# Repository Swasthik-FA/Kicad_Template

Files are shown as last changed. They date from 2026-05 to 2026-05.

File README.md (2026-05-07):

<!--PCB_BLOCK-->
<table align="center">
  <tr>
    <td align="center">
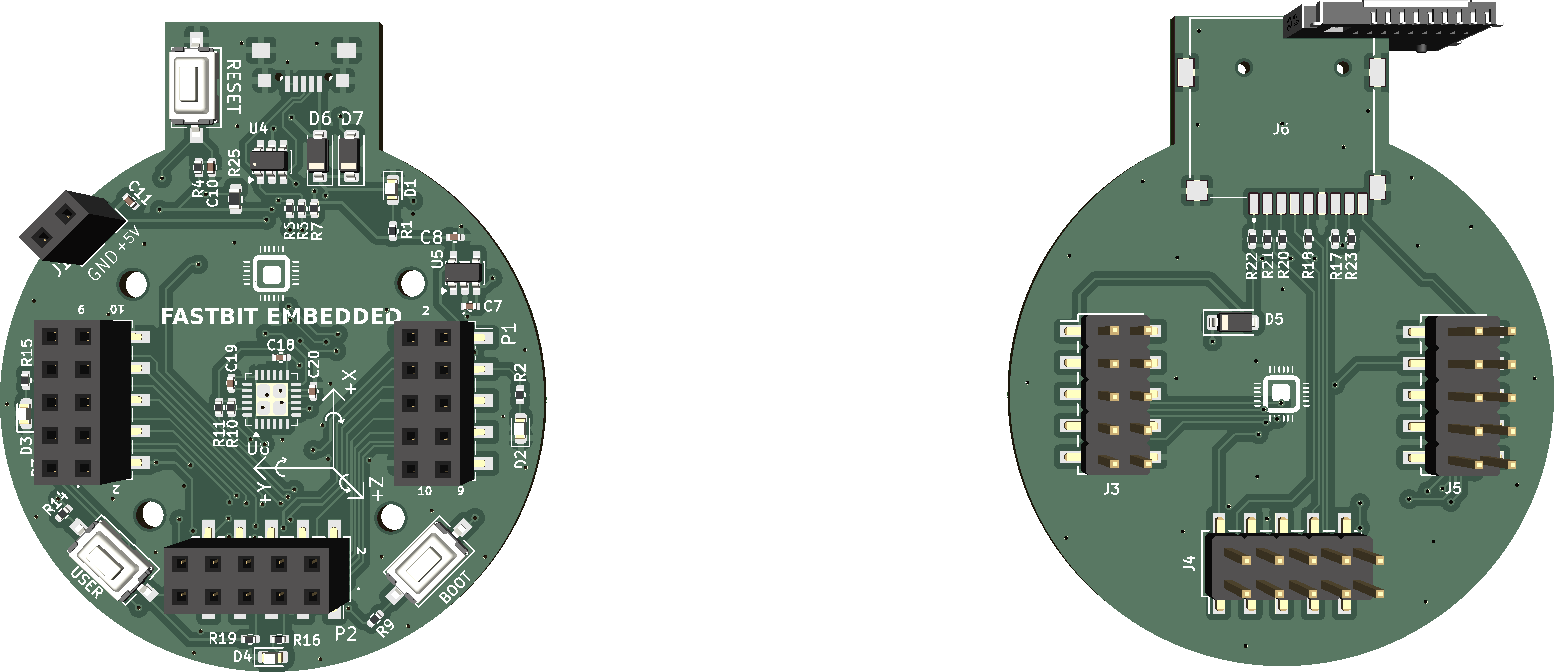
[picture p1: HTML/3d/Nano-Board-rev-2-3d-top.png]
Front
      
      <br><sub><b>Front</b></sub>
    </td>
    <td align="center">
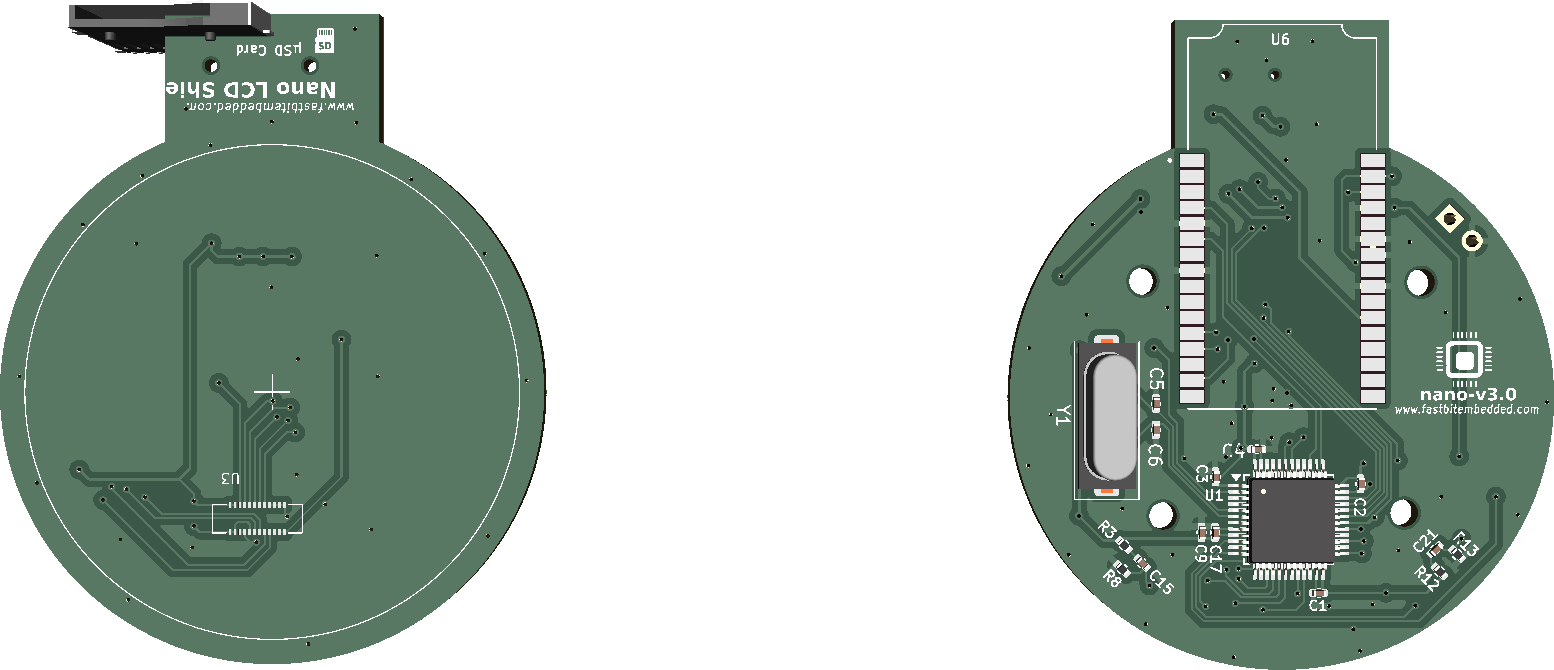
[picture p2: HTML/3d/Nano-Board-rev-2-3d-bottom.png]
Back
      
      <br><sub><b>Back</b></sub>
    </td>
  </tr>
</table>

***

## SPECIFICATIONS

| Parameter | Value |
| --- | --- |
| Dimensions | 125.74 x 53.08 mm |
<!--/PCB_BLOCK-->

***

## DIRECTORY STRUCTURE

    .
    ├─ .github/workflows  # CI pipeline (feature push, PR gates, release)
    ├─ HTML               # Generated reports / Pages site (CI output)
    ├─ config             # KiBot YAML configs and report templates
    │  ├─ kibot           # Orchestrator + per-output YAMLs
    │  └─ web             # Themed CSS and Three.js 3D viewer template
    ├─ docs               # Project images and documentation assets
    ├─ hardware           # KiCad project (source of truth)
    ├─ manufacturing      # Auto-generated fabrication artifacts
    └─ scripts            # Helper scripts (rename project, GLB export)

<p align="center" width="100%">
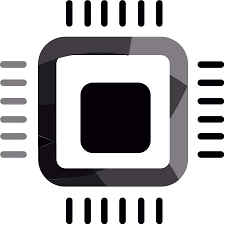
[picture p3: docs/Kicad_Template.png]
  
</p>

<h1 align="center"><!--REPO_NAME-->Kicad_Template<!--/REPO_NAME--></h1>

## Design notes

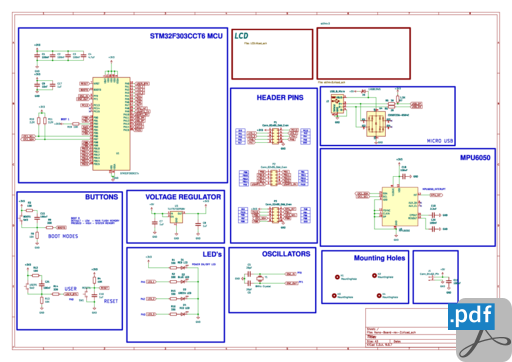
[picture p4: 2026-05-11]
HTML/HTML/images/cat_pdf_schematic_Nano-Board-rev-2-schematic.png

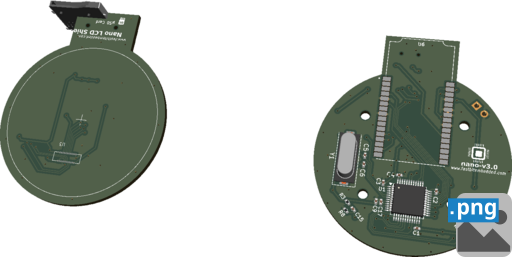
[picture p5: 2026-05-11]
HTML/HTML/images/cat_png_3d_angled_bottom_Nano-Board-rev-2-3d-angled-bottom.png

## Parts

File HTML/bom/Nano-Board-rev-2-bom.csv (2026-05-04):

Reference | Value | Footprint | Quantity | LCSC Part # | MPN | Manufacturer
BOOT1 | SW3 | SW_Tactile_SPST_NO_Straight_CK_PTS636Sx25SMTRLFS | 1 | C318938 | TS1101-C-W | C318936 TS1101-C-W
C5 C6 | 20pF | C_0402_1005Metric | 2 | C1554 | 0402CG200J50 0NT | FH (Guangdong Fenghua Advanced Tech 0402CG200J500NT
C19 | 2.2nF | C_0402_1005Metric | 1 | C338130 | 0402B222K500CT | Walsin Tech Corp 0402B222K500CT
C9 | 10nF | C_0402_1005Metric | 1 | C60133 | CC0402KRX7R9BB | YAGEO CC0402KRX7R9BB103
C1 C2 C3 C11 C15 C18 C20 C21 | 100nF | C_0402_1005Metric | 8 | C48579247 | TCC0402X5R1 04Z160A | CCTC 0402X7R104K160NT
C7 C8 C10 C17 | 1uF | C_0402_1005Metric | 4 | C7503519 | CL05A105KP5NNNC | CGA0402X5R105K6R3GT Samsung
C4 | 4.7uF | C_0402_1005Metric | 1 | C48579247 | TCC0402X5R4 75M6R3AT | CCTC 0402X7R104K160NT
D5 D6 D7 | 1N5819WS | D_SOD-123 | 3 | C191023 |  | 1N5819WS
D2 | BLUE LED | LED_0603_1608Metric | 1 | C165977 | BLHB337A-AV-TRB | BrtLed(Bright LED Elec) BL-HB337A-AV-TRB
D3 | GREEN LED | LED_0603_1608Metric | 1 | C434449 | SZYY0402YG | Yongyu Photoelectric SZYY0402YG
D1 D4 | RED LED | LED_0603_1608Metric | 2 | C165980 | BLHUB37A-AV-TRB | BrtLed(Bright LED Elec) BL-HUB37A-AV-TRB
J1 | Conn_01x02_Pin | PinSocket_1x02_P2.54mm_Vertical | 1
J3 J4 J5 | Conn_02x05_Odd_Even | PinHeader_2x05_P2.54mm_Vertical_SMD | 3 | C3294463 | PZ254-2-05-S | HCTL PZ254-2-05-S
J6 | Micro_SD_Card_Det1 | CUI_MSD-1-A | 1 | C52750848 | MLD-TF PUSH-H18 | MLD-TF PUSH-H18
J2 | USB_B_Micro | micro_USB | 1 | C25503144 | KH2.54FH1X12P-H8.5 | HCTL 051T-4BH89-S
P1 P2 P3 | Conn_02x05_Odd_Even | PinSocket_2x05_P2.54mm_Vertical_SMD | 3 | C843271 | 2.54-2*5P | Liansheng 2.54-2*5P
R25 | 0 | R_0603_1608Metric | 1
R5 R6 | 20 | R_0402_1005Metric | 2 | C138031 | RC0402FR-0720RL | YAGEO RC0402FR-0720RL
R3 R12 | 100 | R_0402_1005Metric | 2 | C3017466 | SCR0402J100R | VO SCR0402J100R
R1 R2 R9 R14 R15 R16 | 330 | R_0402_1005Metric | 6 | C2906929 | FRC0402J331 TS | FOJAN FRC0402J331 TS
R7 | 1.5K | R_0402_1005Metric | 1 | C2929900 | FRC0402J152TS | FOJAN FRC0402J152TS
R10 R11 | 2.2K | R_0402_1005Metric | 2 | C100309 | CR0402FF2201G | LIZ Elec CR0402FF2201G
R8 R13 R17 R18 R19 R20 R21 R22 R23 | 10K | R_0402_1005Metric | 9 | C51035904 | SCR0402F10K | VO CL0402JN10KP
R4 | 10K | R_0402_1005Metric | 1 | C51035904 | SCR0402J100K | VO CL0402JN10KP
RESET1 | SW1 | SW_Tactile_SPST_NO_Straight_CK_PTS636Sx25SMTRLFS | 1 | C318938 | TS1101-C-W | C318936 TS1101-C-W
U4 | CDSOT236-0504C | SOT-23-6 | 1 | C41409337 | CDSOT236- 0504C | Leiditech CDSOT236-0504C-ES
U8 | MPU6050 | Mpu6050 | 1 |  | MPU-6050 | InvenSense MPU-6050
U6 | STLINK-V3MODS | MODULE_STLINK-V3MODS | 1 |  |  | ST Microelectronics
U1 | STM32F303CCTx | LQFP-48_7x7mm_P0.5mm | 1 | C81523 | STM32F303CC T6 | STMicroelectro nics STM32F303CC T6
U5 | TLV75733PDBV | SOT-23-5 | 1 | C485517 |  | TLV75733PDBVR
U3 | ~ | OK-24F024-04 | 1
USER1 | SW2 | SW_Tactile_SPST_NO_Straight_CK_PTS636Sx25SMTRLFS | 1 | C318938 | TS1101-C-W | C318936 TS1101-C-W
Y1 | 8MHz Crystal | Crystal_SMD_HC49-SD | 1 | C12674 | X49SM8MSD2 | YXC X49SM8MSD2SC

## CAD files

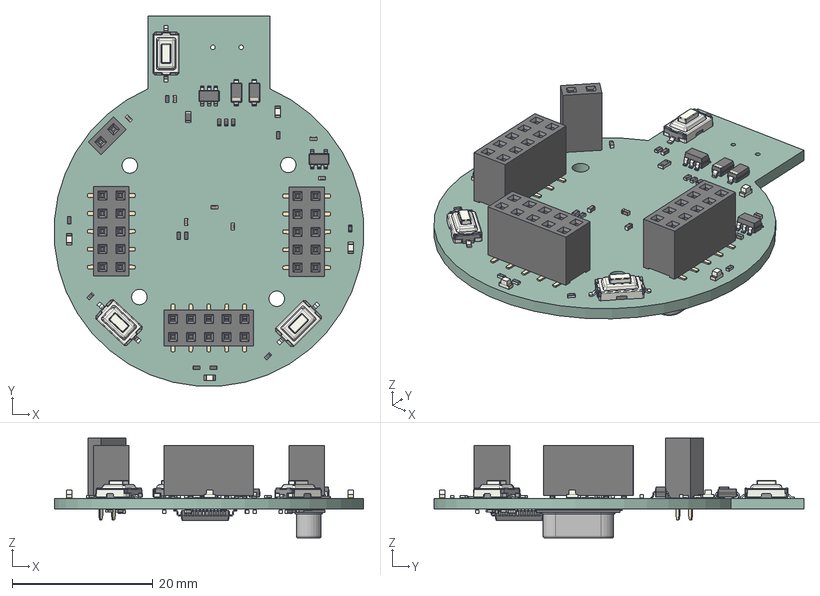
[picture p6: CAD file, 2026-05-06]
HTML/3d/Nano-Board-rev-2.step
43.9 x 52.5 x 14.2 mm
LED_0603_1608Metric x 4
R_0402_1005Metric x 17
C_0402_1005Metric x 17
R_0603_1608Metric
PinSocket_2x05_P2.54mm_Vertical_SMD x 3
SW_Tactile_SPST_NO_Straight_CK_PTS636Sx25SMTRLFS x 3
SOT-23-6
D_SOD-123 x 2
SOT-23-5
PinSocket_1x02_P2.54mm_Vertical
Crystal_SMD_HC49-SD
LQFP-48_7x7mm_P0.5mm
kibot_6w4liwqz_PCB

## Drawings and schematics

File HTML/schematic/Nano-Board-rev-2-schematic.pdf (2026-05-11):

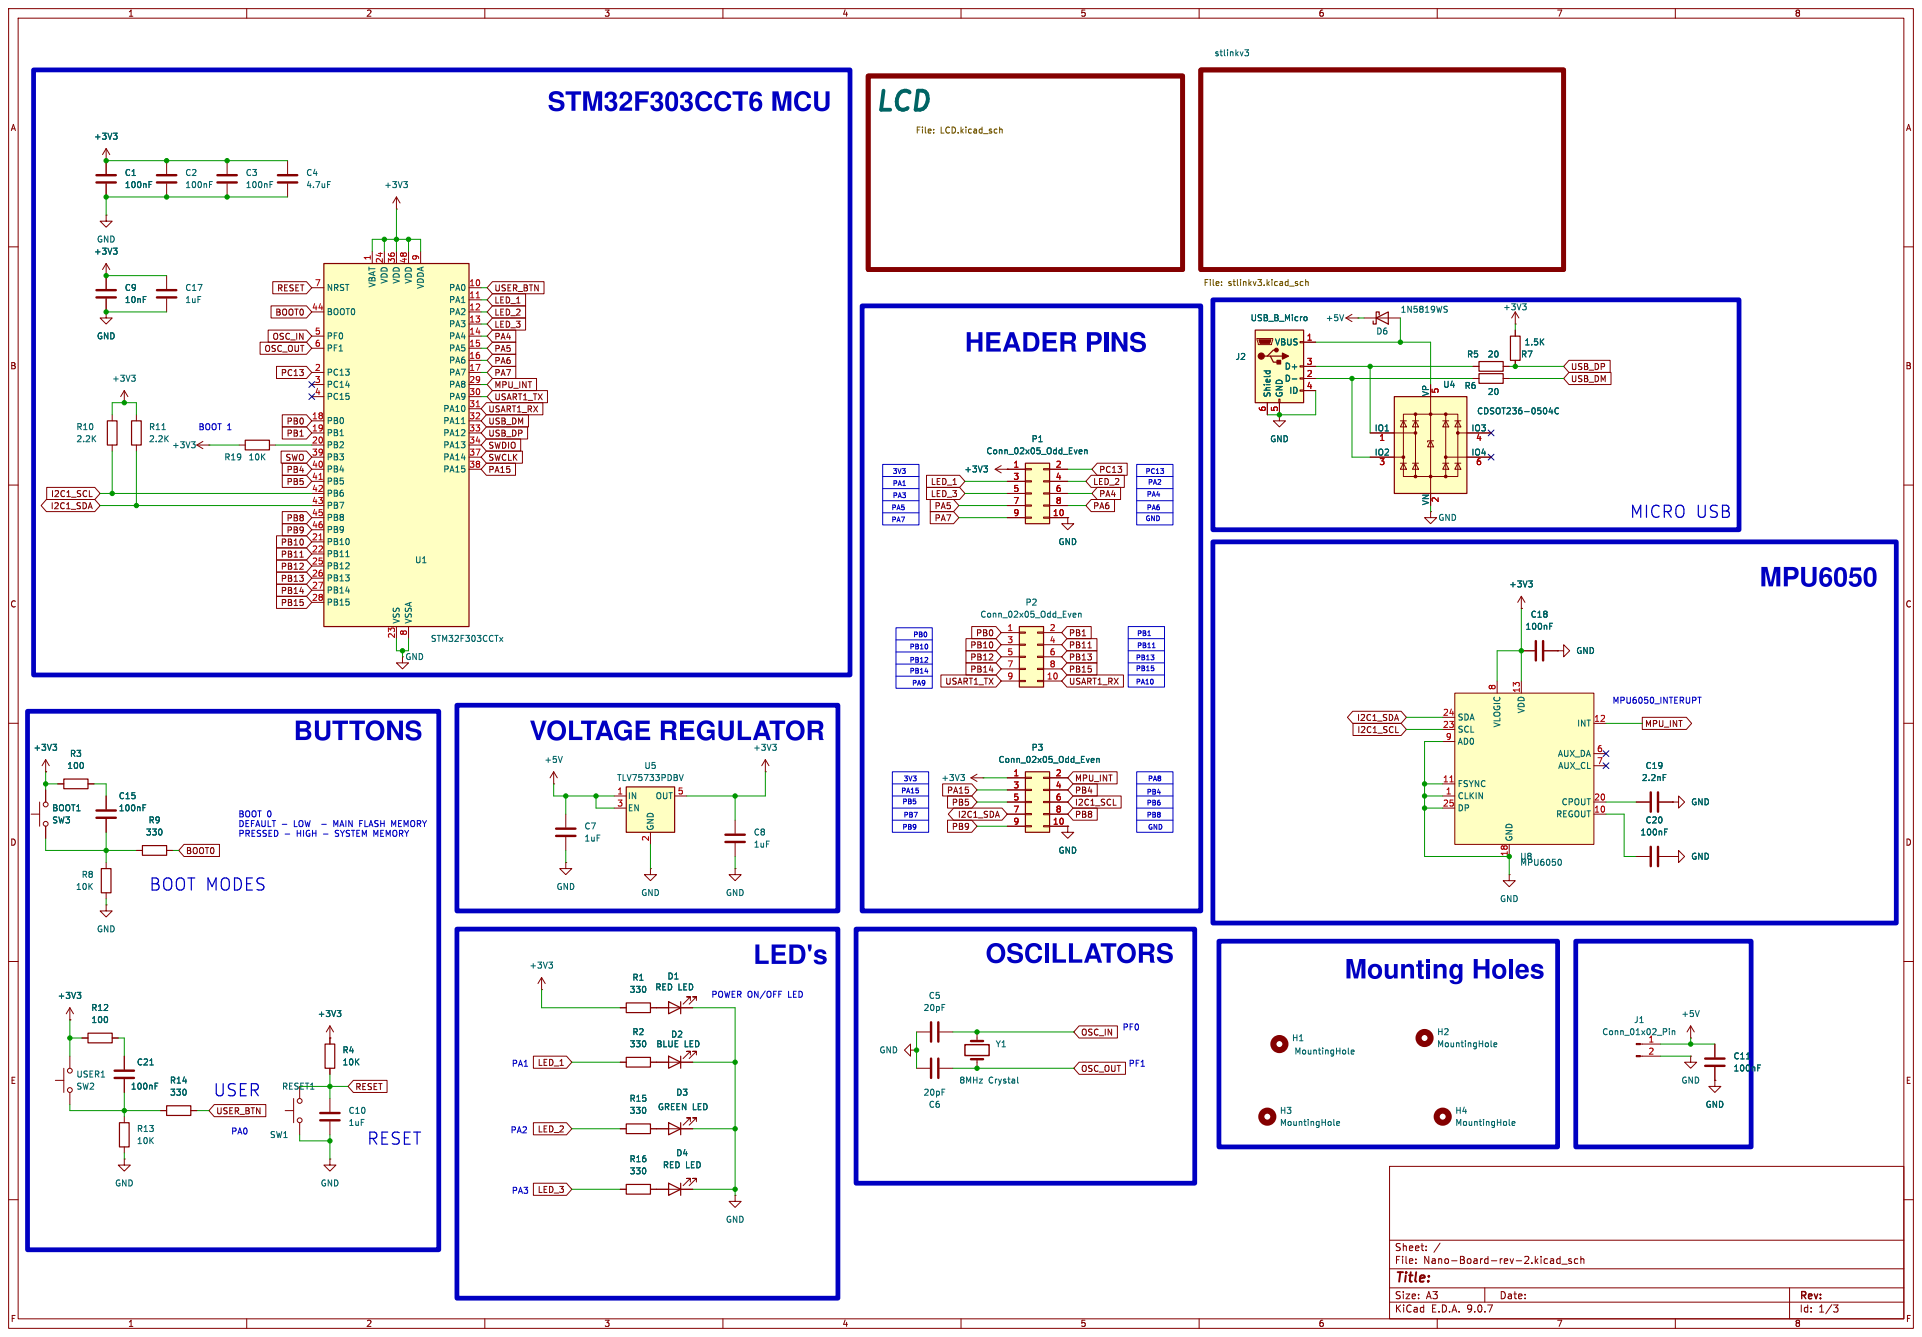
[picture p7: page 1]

PA2 BOOT 0 DEFAULT - LOW - MAIN FLASH MEMORY

PA6 POWER ON/OFF LED

8 VDD 13 U8 MPU6050
INT 12 AUX_DA 6 AUX_CL 7 CPOUT 20 REGOUT 10 VLOGIC

PRESSED - HIGH - SYSTEM MEMORY BOOT MODES
10K GND

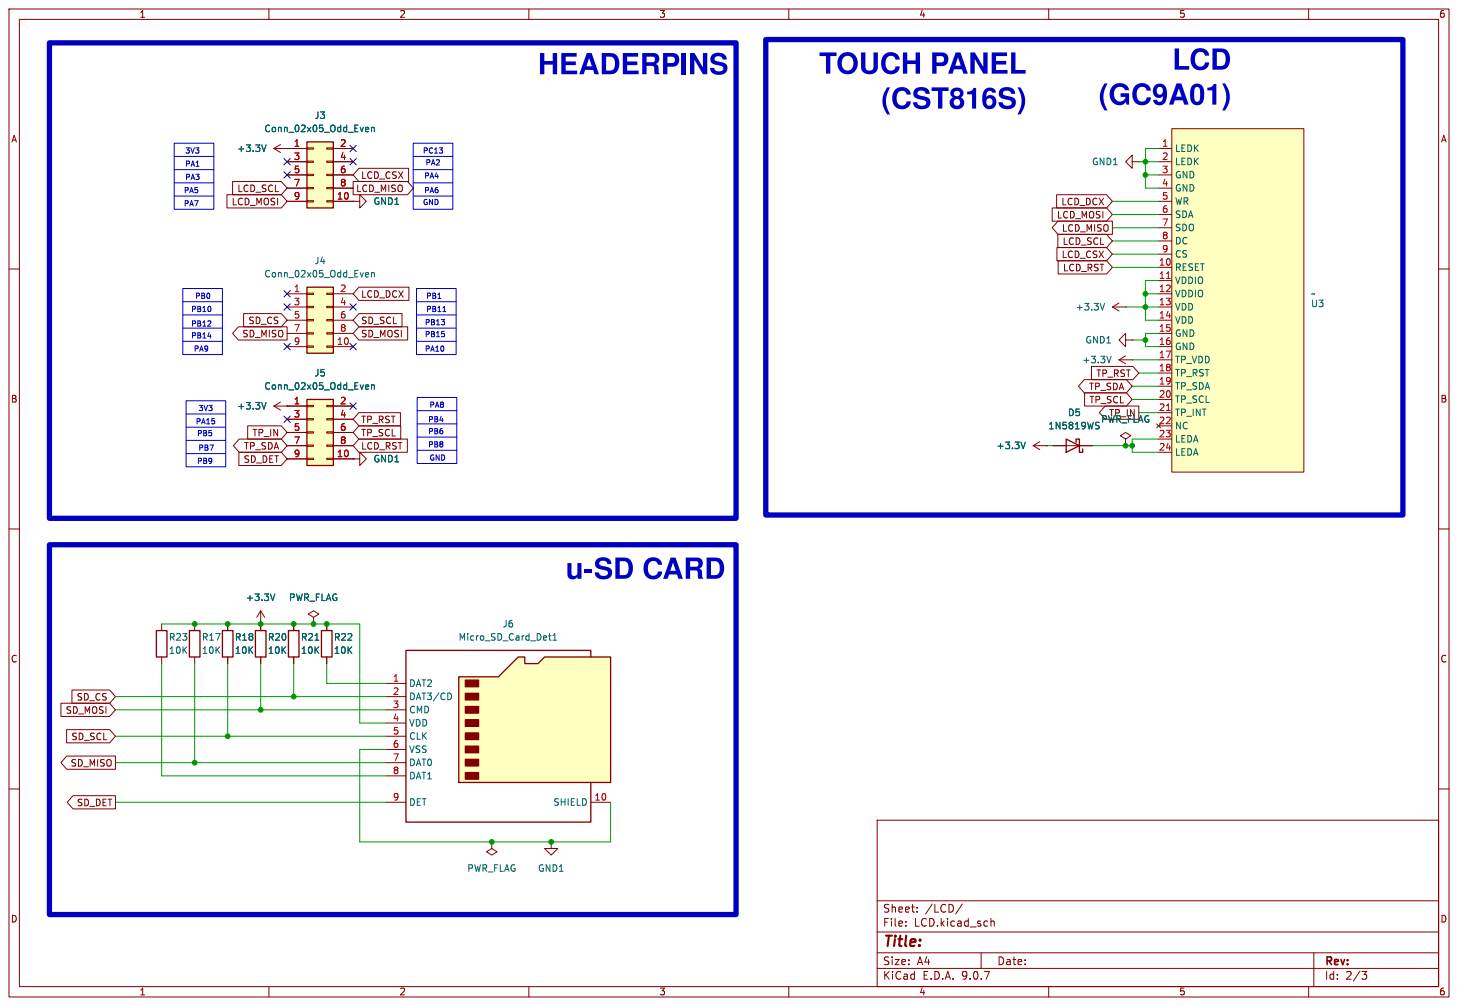
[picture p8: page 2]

Id: 2/3 Title: File: LCD.kicad_sch Sheet: /LCD/

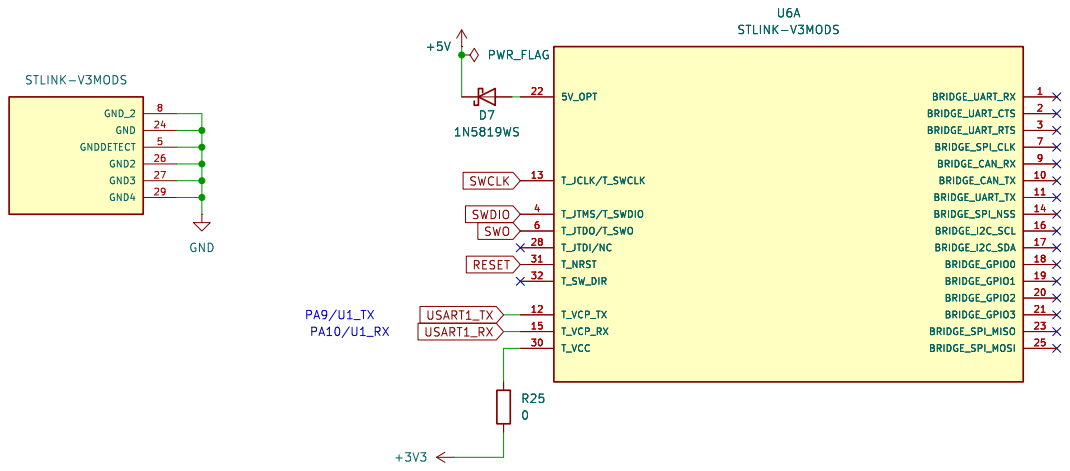
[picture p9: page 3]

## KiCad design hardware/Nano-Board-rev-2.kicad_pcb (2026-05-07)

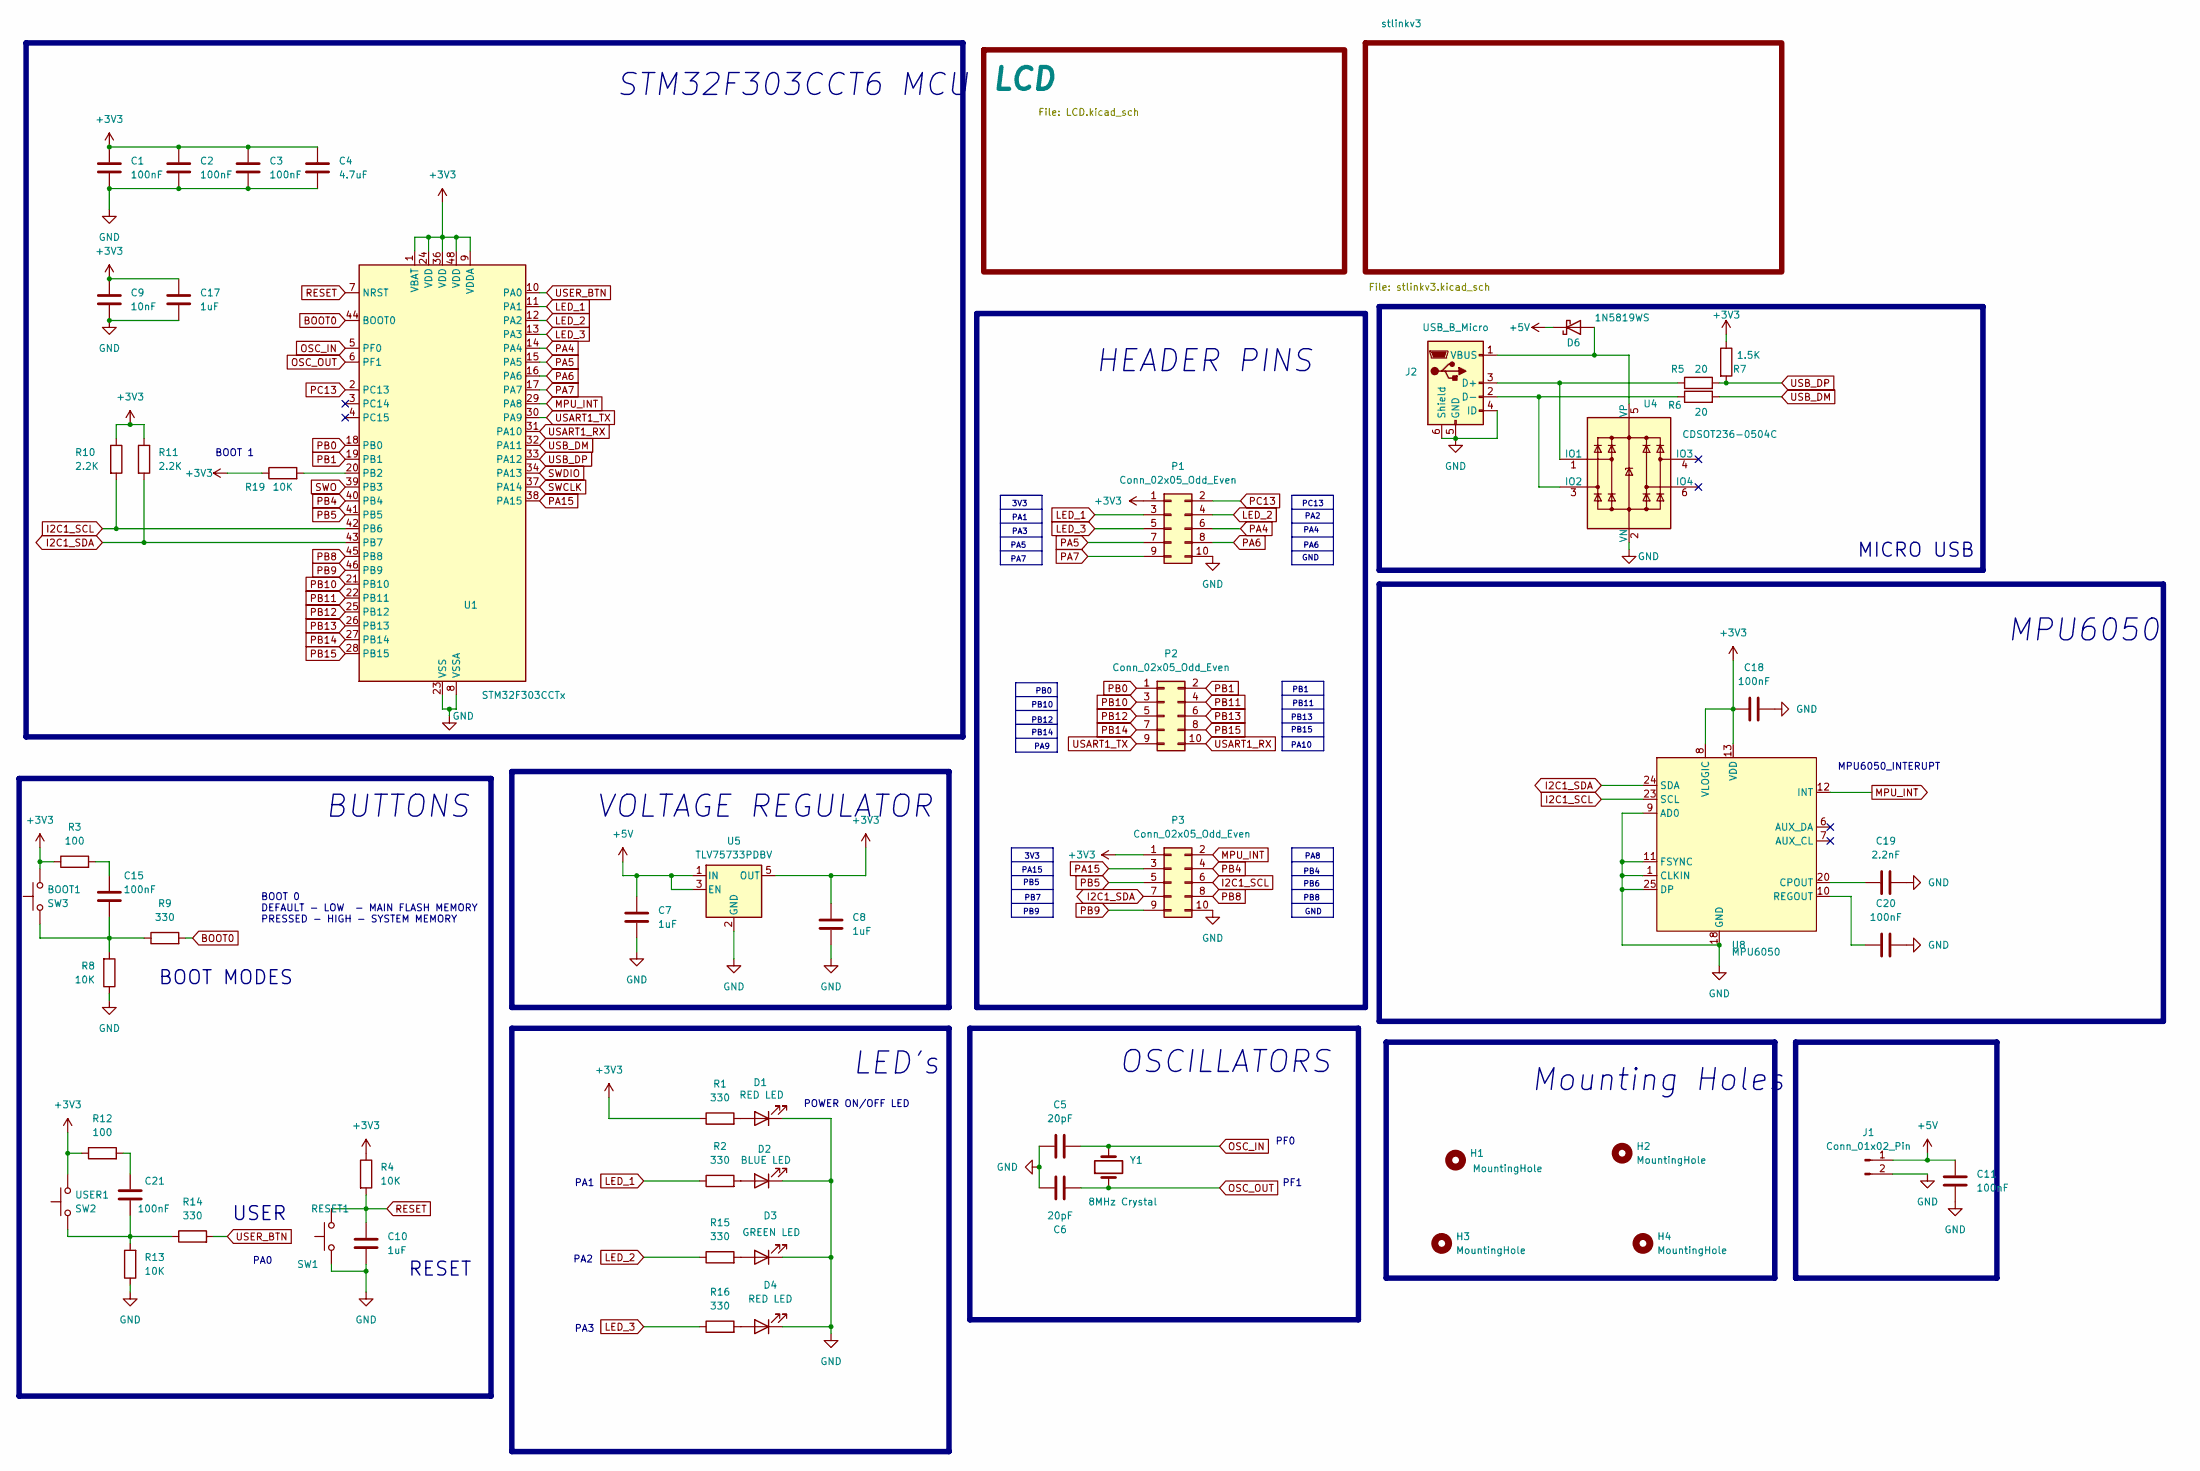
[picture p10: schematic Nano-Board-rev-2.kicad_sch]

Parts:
BOOT1: SW3; SW_Tactile_SPST_NO_Straight_CK_PTS636Sx25SMTRLFS; MPN TS1101-C-W; LCSC C318938
C1, C2, C3, C15, C18, C20, C21: 100nF; C_0402_1005Metric; MPN TCC0402X5R1 04Z160A; LCSC C48579247
C4: 4.7uF; C_0402_1005Metric; MPN TCC0402X5R4 75M6R3AT; LCSC C48579247
C5, C6: 20pF; C_0402_1005Metric; MPN 0402CG200J50 0NT; LCSC C1554
C7, C8: 1uF; C_0402_1005Metric; LCSC C7503519
C9: 10nF; C_0402_1005Metric; MPN CC0402KRX7R9BB; LCSC C60133
C10, C17: 1uF; C_0402_1005Metric; MPN CL05A105KP5NNNC; LCSC C7503519
C11: 100nF; C_0402_1005Metric
C19: 2.2nF; C_0402_1005Metric; MPN 0402B222K500CT; LCSC C338130
D1, D4: RED LED; LED_0603_1608Metric; MPN BLHUB37A-AV-TRB; LCSC C165980
D2: BLUE LED; LED_0603_1608Metric; MPN BLHB337A-AV-TRB; LCSC C165977
D3: GREEN LED; LED_0603_1608Metric; MPN SZYY0402YG; LCSC C434449
D6: 1N5819WS; D_SOD-123; LCSC C191023
H1, H2, H3, H4: MountingHole; MountingHole_2.2mm_M2
J1: Conn_01x02_Pin; PinSocket_1x02_P2.54mm_Vertical
J2: USB_B_Micro; micro_USB; MPN KH2.54FH1X12P-H8.5; LCSC C25503144
P1, P2, P3: Conn_02x05_Odd_Even; PinSocket_2x05_P2.54mm_Vertical_SMD; MPN 2.54-2*5P; LCSC C843271
R1, R2, R9, R14, R15, R16: 330; R_0402_1005Metric; MPN FRC0402J331 TS; LCSC C2906929
R3, R12: 100; R_0402_1005Metric; MPN SCR0402J100R; LCSC C3017466
R4: 10K; R_0402_1005Metric; MPN SCR0402J100K; LCSC C51035904
R5, R6: 20; R_0402_1005Metric; MPN RC0402FR-0720RL; LCSC C138031
R7: 1.5K; R_0402_1005Metric; MPN FRC0402J152TS; LCSC C2929900
R8, R13, R19: 10K; R_0402_1005Metric; MPN SCR0402F10K; LCSC C51035904
R10, R11: 2.2K; R_0402_1005Metric; MPN CR0402FF2201G; LCSC C100309
RESET1: SW1; SW_Tactile_SPST_NO_Straight_CK_PTS636Sx25SMTRLFS; MPN TS1101-C-W; LCSC C318938
U1: STM32F303CCTx; LQFP-48_7x7mm_P0.5mm; MPN STM32F303CC T6; LCSC C81523
U4: CDSOT236-0504C; SOT-23-6; MPN CDSOT236- 0504C; LCSC C41409337
U5: TLV75733PDBV; SOT-23-5; LCSC C485517
U8: MPU6050; Mpu6050; MPN MPU-6050
USER1: SW2; SW_Tactile_SPST_NO_Straight_CK_PTS636Sx25SMTRLFS; MPN TS1101-C-W; LCSC C318938
Y1: 8MHz Crystal; Crystal_SMD_HC49-SD; MPN X49SM8MSD2; LCSC C12674

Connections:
+3V3: BOOT1.2, C1.1, C2.1, C3.1, C4.1, C8.1, C9.1, C17.1, C18.1, P1.1, P3.1, R1.1, R3.1, R4.1, R7.1, R10.1, R11.1, R12.1, R19.1, U1.1 (VBAT), U1.9 (VDDA), U1.24 (VDD), U1.36 (VDD), U1.48 (VDD), U5.5 (OUT), U8.8 (VLOGIC), U8.13 (VDD), USER1.2; also elsewhere on the board
+5V: C7.1, C11.1, D6.1 (K), J1.1, U5.1 (IN), U5.3 (EN); also elsewhere on the board
BOOT0: R9.2, U1.44 (BOOT0)
GND: C1.2, C2.2, C3.2, C4.2, C5.1, C6.1, C7.2, C8.2, C9.2, C10.2, C11.2, C17.2, C18.2, C19.2, C20.2, D1.1 (K), D2.1 (K), D3.1 (K), D4.1 (K), J1.2, J2.4 (ID), J2.5 (GND), J2.6 (Shield), P1.10, P3.10, R8.1, R13.1, RESET1.1, U1.8 (VSSA), U1.23 (VSS), U1.35 (VSS), U1.47 (VSS), U4.2 (VN), U5.2 (GND), U8.1 (CLKIN), U8.9 (AD0), U8.11 (FSYNC), U8.18 (GND), U8.25 (DP); also elsewhere on the board
I2C1_SCL: P3.6, R10.2, U1.42 (PB6), U8.23 (SCL)
I2C1_SDA: P3.7, R11.2, U1.43 (PB7), U8.24 (SDA)
LED_1: P1.3, R2.1, U1.11 (PA1)
LED_2: P1.4, R15.1, U1.12 (PA2)
LED_3: P1.5, R16.1, U1.13 (PA3)
MPU_INT: P3.2, U1.29 (PA8), U8.12 (INT)
unnamed 18: BOOT1.1, C15.2, R8.2, R9.1; also elsewhere on the board
unnamed: C15.1, R3.2
unnamed: C21.1, R12.2
unnamed 21: C21.2, R13.2, R14.1, USER1.1; also elsewhere on the board
unnamed: D1.2 (A), R1.2
unnamed: D2.2 (A), R2.2
unnamed: D3.2 (A), R15.2
unnamed: D4.2 (A), R16.2
unnamed: D6.2 (A), J2.1 (VBUS), U4.5 (VP)
unnamed: J2.3 (D+), R5.1, U4.1 (IO1)
unnamed: J2.2 (D-), R6.1, U4.3 (IO2)
unnamed: R19.2, U1.20 (PB2)
unnamed: C19.1, U8.20 (CPOUT)
unnamed: C20.1, U8.10 (REGOUT)
OSC_IN: C5.2, U1.5 (PF0), Y1.2
OSC_OUT: C6.2, U1.6 (PF1), Y1.1
PA4: P1.6, U1.14 (PA4)
PA5: P1.7, U1.15 (PA5)
PA6: P1.8, U1.16 (PA6)
PA7: P1.9, U1.17 (PA7)
PA15: P3.3, U1.38 (PA15)
PB0: P2.1, U1.18 (PB0)
PB1: P2.2, U1.19 (PB1)
PB4: P3.4, U1.40 (PB4)
PB5: P3.5, U1.41 (PB5)
PB8: P3.8, U1.45 (PB8)
PB9: P3.9, U1.46 (PB9)
PB10: P2.3, U1.21 (PB10)
PB11: P2.4, U1.22 (PB11)
PB12: P2.5, U1.25 (PB12)
PB13: P2.6, U1.26 (PB13)
PB14: P2.7, U1.27 (PB14)
PB15: P2.8, U1.28 (PB15)
PC13: P1.2, U1.2 (PC13)
RESET: C10.1, R4.2, RESET1.2, U1.7 (NRST); also elsewhere on the board
SWCLK: U1.37 (PA14); also elsewhere on the board
SWDIO: U1.34 (PA13); also elsewhere on the board
SWO: U1.39 (PB3); also elsewhere on the board
USART1_RX: P2.10, U1.31 (PA10); also elsewhere on the board
USART1_TX: P2.9, U1.30 (PA9); also elsewhere on the board
USB_DM: R6.2, U1.32 (PA11)
USB_DP: R5.2, R7.2, U1.33 (PA12)
USER_BTN: R14.2, U1.10 (PA0)

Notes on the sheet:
PB11
PB12
PF0
PB7
PA10
PB6
PC13
STM32F303CCT6 MCU
POWER ON/OFF LED
PA1
3V3
RESET
Mounting Holes
BUTTONS
BOOT MODES
PB15
PA3
PB9
MICRO USB
PB5
PA7
PB13
BOOT 1
PF1
PB4
VOLTAGE REGULATOR
GND
PA9
MPU6050
MPU6050_INTERUPT
PA2
PA15
PB0
PA8
LED's
PB14
PB8
USER
PA4
PB1

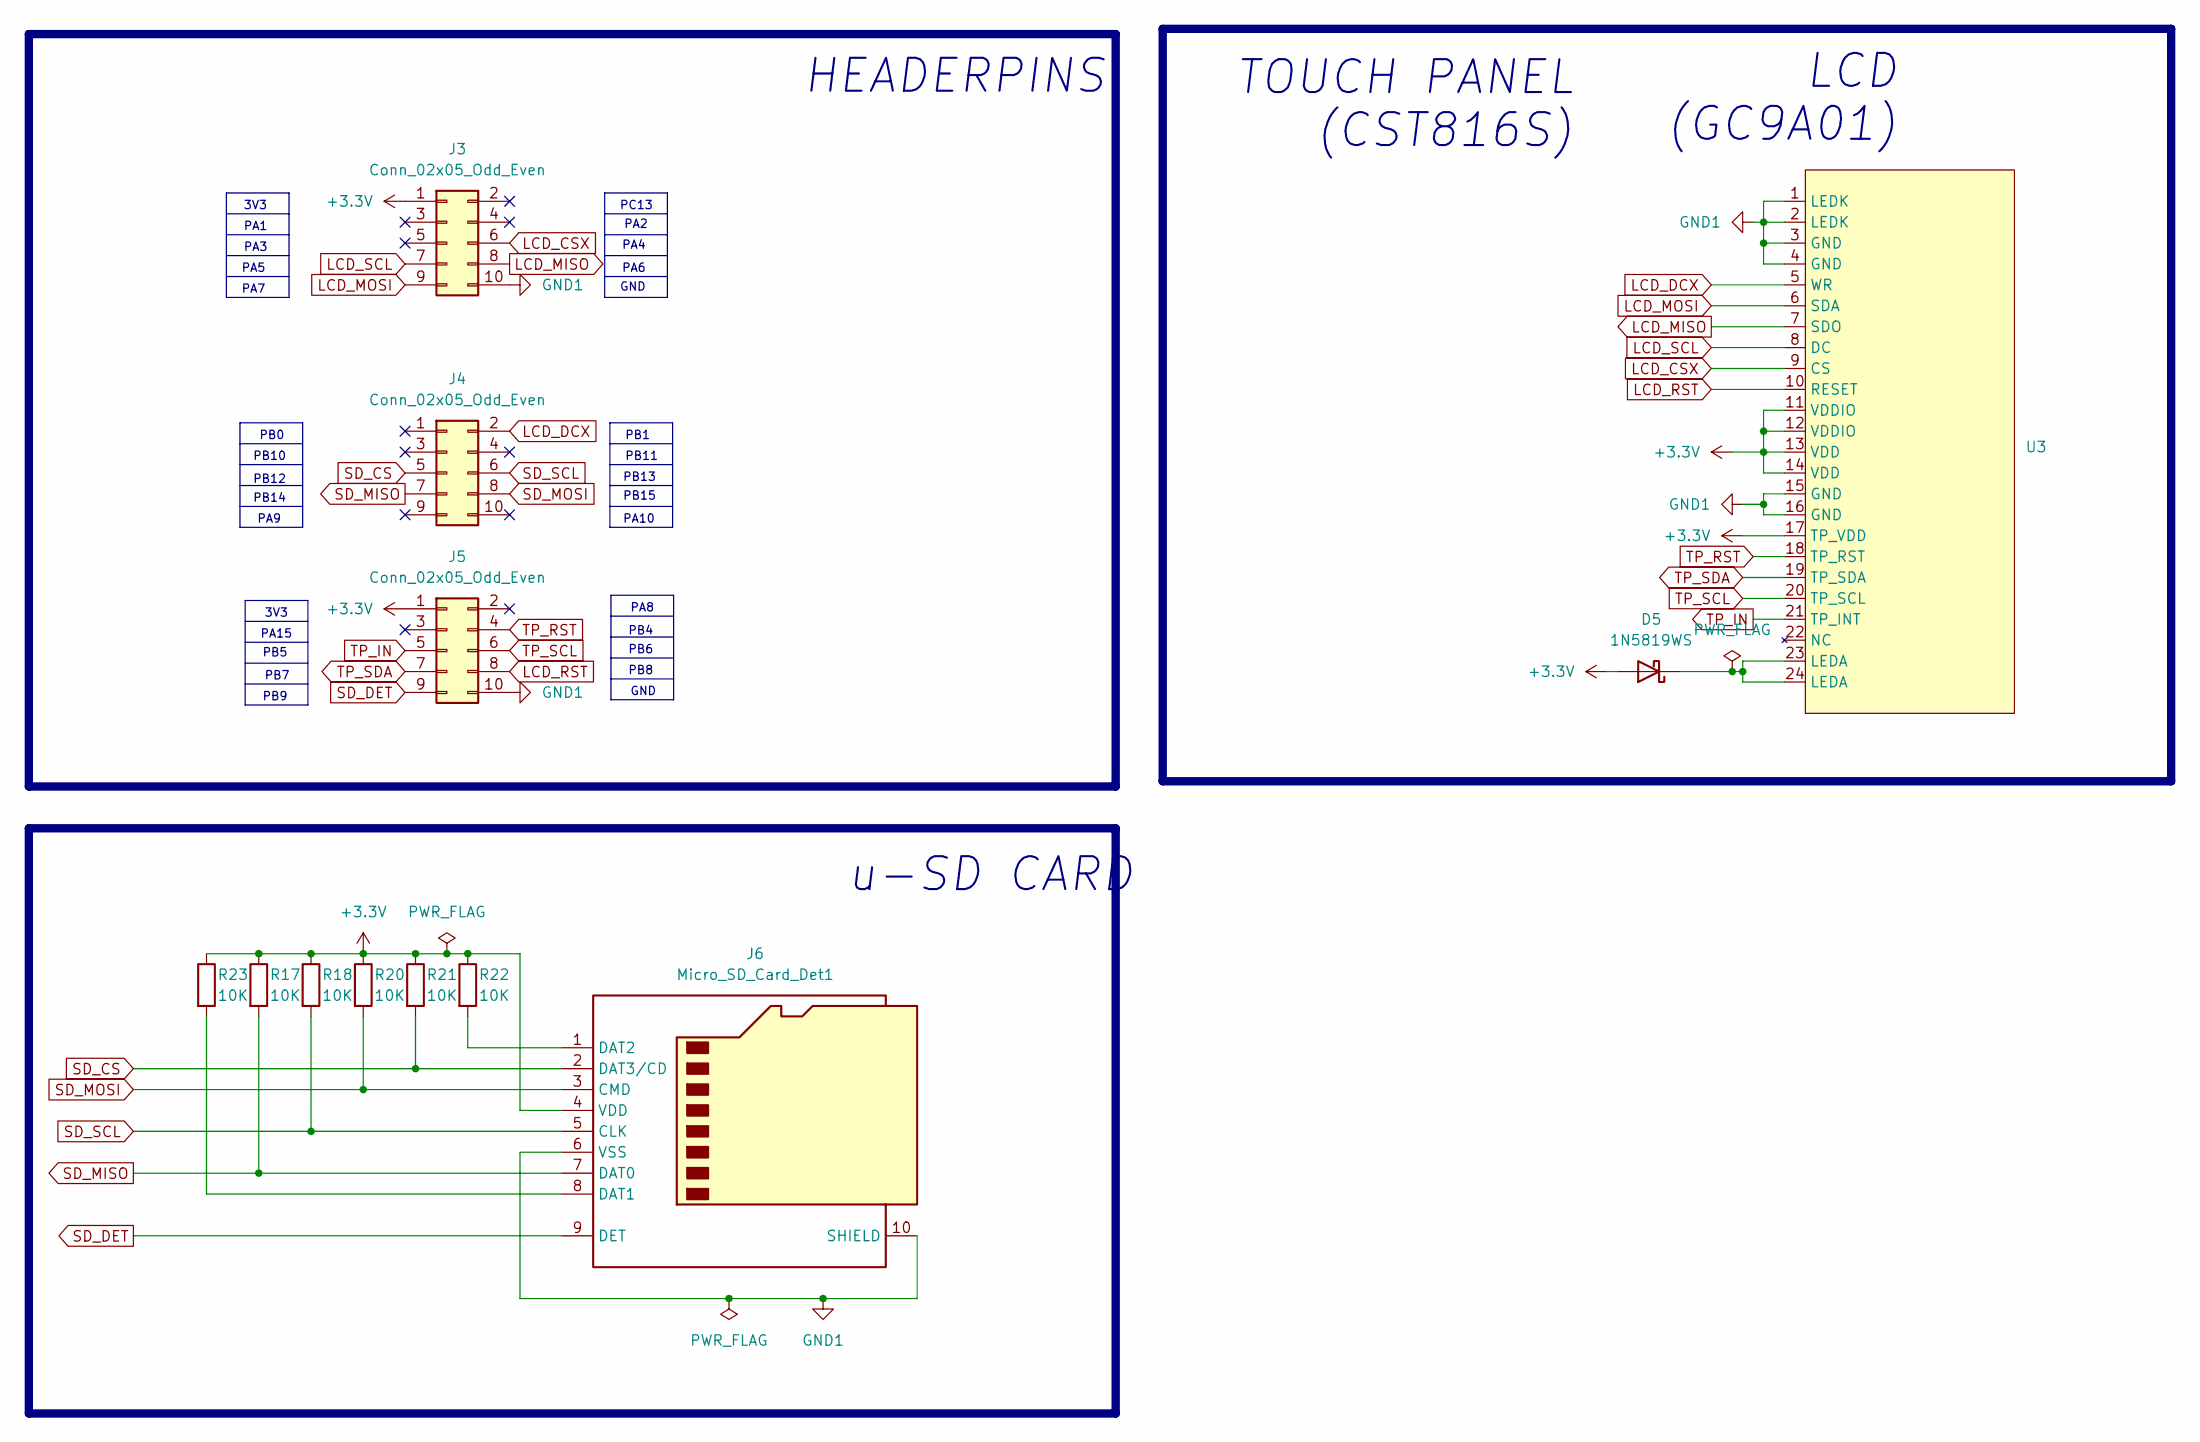
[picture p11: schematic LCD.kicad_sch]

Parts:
D5: 1N5819WS; D_SOD-123; LCSC C191023
J3, J4, J5: Conn_02x05_Odd_Even; PinHeader_2x05_P2.54mm_Vertical_SMD; MPN PZ254-2-05-S; LCSC C3294463
J6: Micro_SD_Card_Det1; CUI_MSD-1-A; MPN MLD-TF PUSH-H18; LCSC C52750848
R17, R18, R20, R21, R22, R23: 10K; R_0402_1005Metric; MPN SCR0402F10K; LCSC C51035904
U3: OK-24F024-04

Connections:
+3.3V: D5.2 (A), J3.1, J5.1, J6.4 (VDD), R17.1, R18.1, R20.1, R21.1, R22.1, R23.1, U3.11 (VDDIO), U3.12 (VDDIO), U3.13 (VDD), U3.14 (VDD), U3.17 (TP_VDD)
GND1: J3.10, J5.10, J6.6 (VSS), J6.10 (SHIELD), U3.1 (LEDK), U3.2 (LEDK), U3.3 (GND), U3.4 (GND), U3.15 (GND), U3.16 (GND)
LCD_CSX: J3.6, U3.9 (CS)
LCD_DCX: J4.2, U3.5 (WR)
LCD_MISO: J3.8, U3.7 (SDO)
LCD_MOSI: J3.9, U3.6 (SDA)
LCD_RST: J5.8, U3.10 (RESET)
LCD_SCL: J3.7, U3.8 (DC)
unnamed: D5.1 (K), U3.23 (LEDA), U3.24 (LEDA)
unnamed: J6.8 (DAT1), R23.2
unnamed: J6.1 (DAT2), R22.2
SD_CS: J4.5, J6.2 (DAT3/CD), R21.2
SD_DET: J5.9, J6.9 (DET)
SD_MISO: J4.7, J6.7 (DAT0), R17.2
SD_MOSI: J4.8, J6.3 (CMD), R20.2
SD_SCL: J4.6, J6.5 (CLK), R18.2
TP_IN: J5.5, U3.21 (TP_INT)
TP_RST: J5.4, U3.18 (TP_RST)
TP_SCL: J5.6, U3.20 (TP_SCL)
TP_SDA: J5.7, U3.19 (TP_SDA)

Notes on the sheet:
TOUCH PANEL (CST816S)
PA4
PB15
PB11
PB14
PA5
PA2
u-SD CARD
PA3
LCD (GC9A01)
PB7
PA1
PA10
PA6
PB12
GND
PB9
PB4
3V3
PB1
PB8
PA8
PA7
PC13
PA9
PB6
PB13
HEADERPINS
PB0
PB10
PB5
PA15

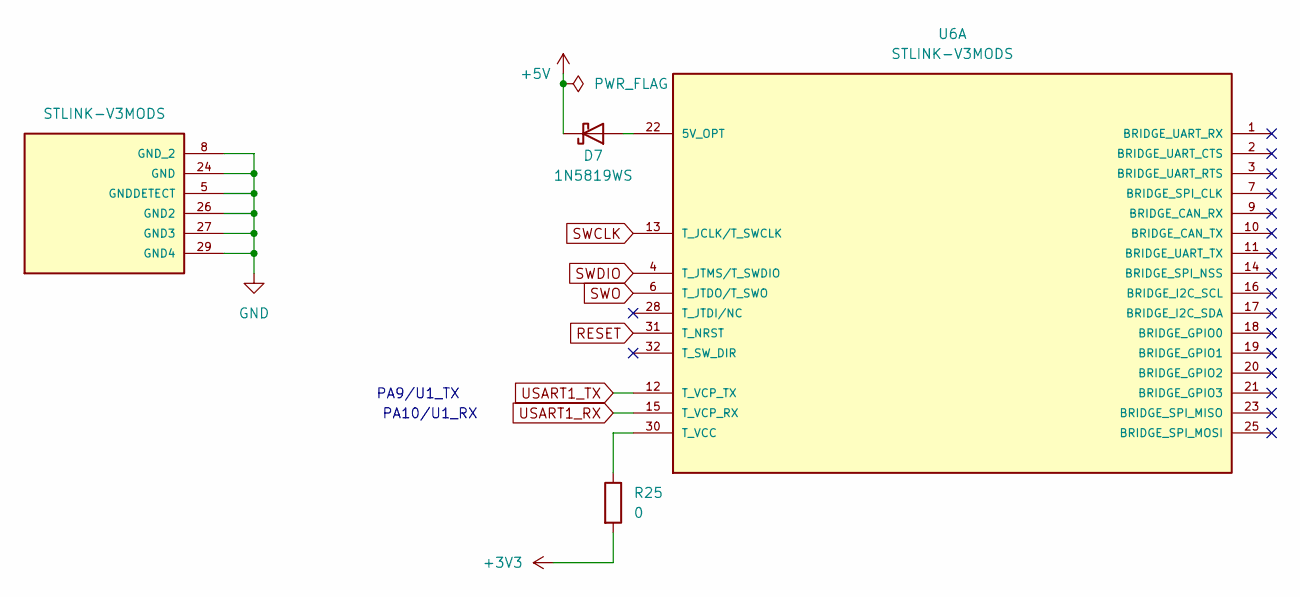
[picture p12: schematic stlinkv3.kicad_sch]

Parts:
D7: 1N5819WS; D_SOD-123; LCSC C191023
R25: 0; R_0603_1608Metric
U6: STLINK-V3MODS; MODULE_STLINK-V3MODS; PARTREV 1

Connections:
+3V3: R25.2; also elsewhere on the board
+5V: D7.1 (K); also elsewhere on the board
GND: U6.5 (GNDDETECT), U6.8 (GND_2), U6.24 (GND), U6.26 (GND2), U6.27 (GND3), U6.29 (GND4); also elsewhere on the board
unnamed: D7.2 (A), U6.22 (5V_OPT)
unnamed: R25.1, U6.30 (T_VCC)
RESET: U6.31 (T_NRST); also elsewhere on the board
SWCLK: U6.13 (T_JCLK/T_SWCLK); also elsewhere on the board
SWDIO: U6.4 (T_JTMS/T_SWDIO); also elsewhere on the board
SWO: U6.6 (T_JTDO/T_SWO); also elsewhere on the board
USART1_RX: U6.15 (T_VCP_RX); also elsewhere on the board
USART1_TX: U6.12 (T_VCP_TX); also elsewhere on the board

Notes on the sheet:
PA9/U1_TX
PA10/U1_RX

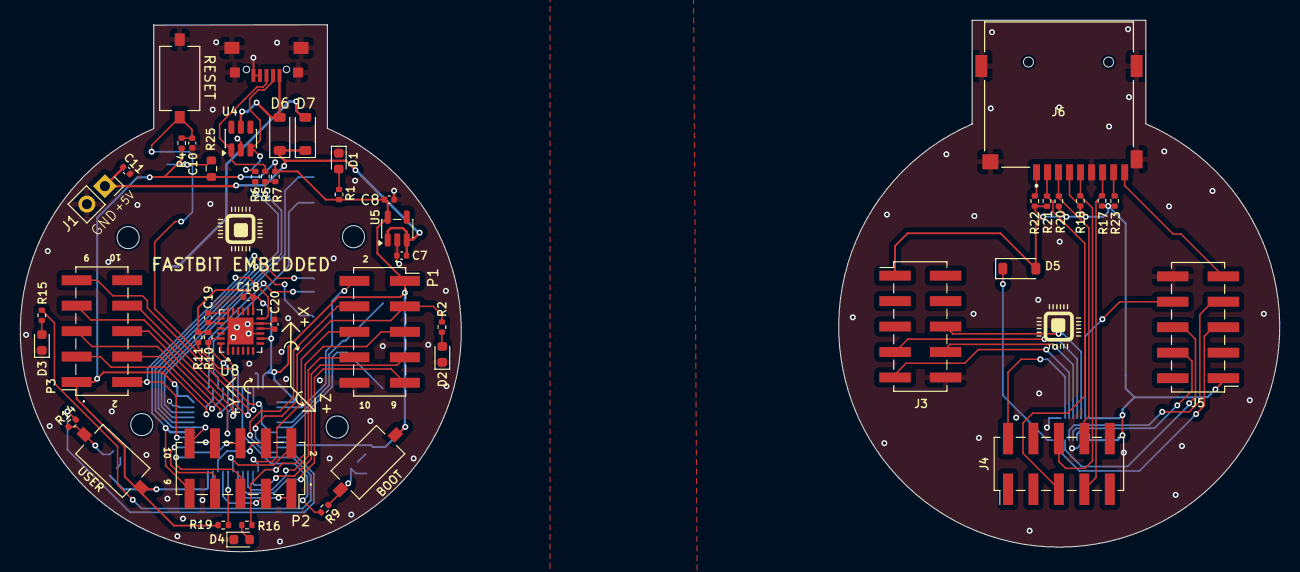
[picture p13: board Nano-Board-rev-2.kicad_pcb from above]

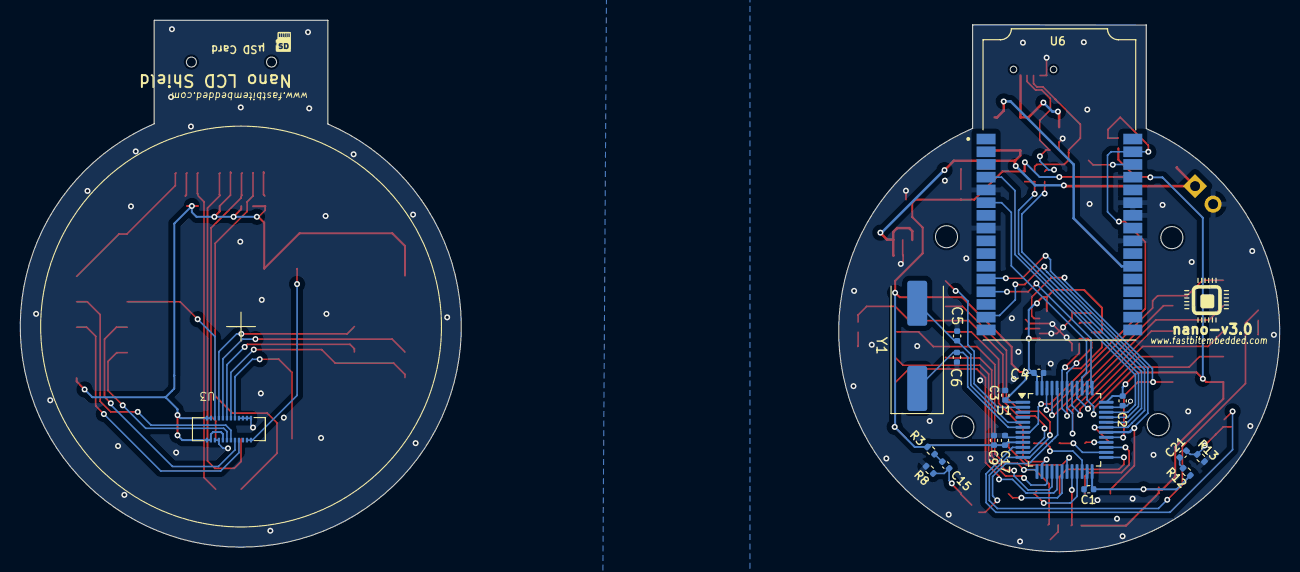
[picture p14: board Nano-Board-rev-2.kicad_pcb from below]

Board: 2 copper layers, 44.0 x 52.6 mm, 71 parts (18 on the bottom side), 75 nets.

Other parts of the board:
BOOT: SW3; SW_Tactile_SPST_NO_Straight_CK_PTS636Sx25SMTRLFS
RESET: SW1; SW_Tactile_SPST_NO_Straight_CK_PTS636Sx25SMTRLFS
USER: SW2; SW_Tactile_SPST_NO_Straight_CK_PTS636Sx25SMTRLFS

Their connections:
+3V3: BOOT.2, USER.2; also elsewhere on the board
GND: RESET.1; also elsewhere on the board
unnamed 18: BOOT.1; also elsewhere on the board
unnamed 21: USER.1; also elsewhere on the board
RESET: RESET.2; also elsewhere on the board

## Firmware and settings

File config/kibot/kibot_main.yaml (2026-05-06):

# ============================================================================
# KiBot main orchestrator
# ----------------------------------------------------------------------------
# Imports all the templated split-config files and defines two groups:
#
#   visual  → schematic PDF + 3 PNG renders + iBOM
#             Used by Stage 1 (feature push). Fast, no ERC/DRC.
#
#   full    → everything: ERC/DRC + schematic PDF + PCB renders + STEP +
#             gerbers + drills + BOM CSV + pick-place + iBOM
#             Used by Stages 2-5 (PR-to-dev/qa/main + release tag).
#
# Invoke with:
#   kibot -c config/kibot/kibot_main.yaml -d output \
#         -e hardware/<project>.kicad_sch -b hardware/<project>.kicad_pcb \
#         <group_name>
#
# Pattern modeled on the Fastbit reference project's kibot_yaml/kibot_main.yaml.
# ============================================================================
kibot:
  version: 1

# ----------------------------------------------------------------------------
# Imports — KiBot resolves paths relative to this file.
# ----------------------------------------------------------------------------
import:
  - file: kibot_globals.yaml

  # Preflights (only run when the workflow does not pass --skip-pre)
  - file: kibot_pre_erc_report.yaml
  - file: kibot_pre_drc_report.yaml

  # Schematic
  - file: kibot_out_pdf_schematic.yaml

  # 3D renders (template imported three times with different views)
  - file: kibot_out_png_3d_viewer.yaml
    definitions:
      NAME: png_3d_top
      COMMENT: 3D viewer PCB render (top)
      SUFFIX: 3d-top
      VIEW: top
      RAYTRACING: false
      ROTATE_X: 0
      ROTATE_Y: 0
      ROTATE_Z: 0
      ZOOM: 0
      WIDTH: 1600
      HEIGHT: 1600
      DIR: 3d
  - file: kibot_out_png_3d_viewer.yaml
    definitions:
      NAME: png_3d_bottom
      COMMENT: 3D viewer PCB render (bottom)
      SUFFIX: 3d-bottom
      VIEW: bottom
      RAYTRACING: false
      ROTATE_X: 0
      ROTATE_Y: 0
      ROTATE_Z: 0
      ZOOM: 0
      WIDTH: 1600
      HEIGHT: 1600
      DIR: 3d
  - file: kibot_out_png_3d_viewer.yaml
    definitions:
      NAME: png_3d_angled_top
      COMMENT: 3D viewer PCB render (angled isometric, top)
      SUFFIX: 3d-angled-top
      VIEW: top
      RAYTRACING: false
      ROTATE_X: 2
      ROTATE_Y: -1
      ROTATE_Z: 1
      ZOOM: -1
      WIDTH: 1600
      HEIGHT: 1600
      DIR: 3d
  - file: kibot_out_png_3d_viewer.yaml
    definitions:
      NAME: png_3d_angled_bottom
      COMMENT: 3D viewer PCB render (angled isometric, bottom)
      SUFFIX: 3d-angled-bottom
      VIEW: bottom
      RAYTRACING: false
      ROTATE_X: 2
      ROTATE_Y: -1
      ROTATE_Z: -1
      ZOOM: -1
      WIDTH: 1600
      HEIGHT: 1600
      DIR: 3d

  # BOM and assembly
  - file: kibot_out_html_ibom.yaml
  - file: kibot_out_csv_bom.yaml
  - file: kibot_out_csv_pos.yaml

  # Manufacturing
  - file: kibot_out_gerber.yaml
  - file: kibot_out_excellon_drill.yaml
  - file: kibot_out_step.yaml

  # Navigation webpage — must come last so it can index everything above.
  - file: kibot_out_navigate_results.yaml
    definitions:
      NAME: html_navigate_results
      COMMENT: Results webpage in HTML format
      DIR: HTML
      TITLE: 'Kicad_Template'
      LOGO: ''
      LOGO_URL: ''

# ----------------------------------------------------------------------------
# Groups — pick the set of outputs to run via positional arg on kibot CLI.
# ----------------------------------------------------------------------------
groups:

  - name: visual
    outputs:
      - pdf_schematic
      - png_3d_top
      - png_3d_bottom
      - png_3d_angled_top
      - png_3d_angled_bottom
      - html_ibom
      - html_navigate_results

  - name: gate_only
    # ERC + DRC preflights only. Preflights run regardless of outputs,
    # so an empty output list gives us a fast gate-only run.
    outputs: []

  - name: schematic_only
    outputs:
      - pdf_schematic
      - csv_bom

  - name: full
    outputs:
      - pdf_schematic
      - png_3d_top
      - png_3d_bottom
      - png_3d_angled_top
      - png_3d_angled_bottom
      - html_ibom
      - csv_bom
      - csv_position
      - step
      - gerbers
      - drill
      - html_navigate_results

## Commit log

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2026-05-02 Remove deprecated KiBot preflight option, fix gitignore
    - Drop ignore_unconnected from preflight blocks in both KiBot configs;
    it triggered W143 deprecation warnings in CI.
    - Escape the leading # in the auto-save gitignore entry so it actually
    ignores the file instead of being read as a comment.
    - Untrack KiCad auto-save marker that should not have been committed.
2026-05-02 Make Stage 1 resilient and add kicad-cli diagnostic
    - Run each KiBot output independently so one failure does not abort
    the whole visual preview. The artifact still uploads everything that
    did succeed.
    - Add a diagnostic step that invokes kicad-cli directly (sch export svg,
    sch export pdf, pcb export svg). KiBot swallows kicad-cli stderr; this
    step lets us see the raw error when the schematic export keeps failing.
    - Use github.run_number instead of github.ref_name in the artifact name;
    ref_name contains a slash on feature/* branches which breaks the name.
2026-05-02 Pin workflow shell to bash in KiBot container
    The inti-cmnb/kicad8_auto_full container's /bin/sh is dash, which
    does not support bash arrays or other bashisms. Stage 1's per-output
    loop hit a parse error on OUTPUTS=( ... ). Add 'defaults.run.shell: bash'
    to all five workflows so every run step uses bash and we get a
    consistent shell across the pipeline.
2026-05-02 Replace flaky SVG schematic export with PDF + 3D PNG renders
    Modeled on the Fastbit reference KiBot project.
    - Drop svg_sch_print from the visual preset. kicad-cli sch export svg
    returns exit 3 with no diagnostics on projects that reference local
    symbol libraries (the reference project avoids this output type for
    the same reason).
    - Keep pdf_sch_print as the schematic preview — same backend, more
    tolerant of unresolved-library edge cases.
    - Add three render_3d PNG outputs (top, bottom, angled isometric) with
    ray_tracing disabled for a fast feature-branch preview.
    - Add a global filters block to suppress noisy W004/W037/W009/W010/W098/W143
    warnings that don't affect output qual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
2026-05-02 Drop KiBot from Stage 1, drive kicad-cli directly
    The KiBot wrapper was returning EXTERNAL_FAIL (17) and WONT_OVERWRITE (12)
    for every output without surfacing the underlying kicad-cli error. The
    reference Fastbit pcb-checks.yaml workflow calls kicad-cli directly for
    the same reason — full visibility into per-command exit codes and
    stderr.
    For the visual preset we now call:
    - kicad-cli sch export pdf (single-doc schematic)
    - kicad-cli pcb export svg (top + bottom layer prints)
    - kicad-cli pcb render (3D top + bottom PNGs)
    Each command is independent. Failures are tolerated; the summary block
    prints exit codes for all five so we can see exactly what worked.
    St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
2026-05-02 Adopt reference Fastbit workflow pattern for image generation
    Mirror the Swasthik_KiBot_Project ci.yaml + kibot_yaml/* approach:
    - Use the official INTI-CMNB/KiBot@v2_dk8 action (replaces the raw
    container). This is what the reference uses for output generation.
    The action provides a configured KiCad 8 + KiBot environment with
    cache3D support — render_3d needs the cached 3D models to work
    reliably, which is why every render_3d invocation in the previous
    attempts returned EXTERNAL_FAIL.
    - Cache the 3D models directory between runs via actions/cache.
    - kibot-visual.yaml now mirrors the reference's render_3d options
    one-for-one (auto_crop, enable_crop_workaround, force_stackup_co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
2026-05-02 Drop schematic PDF from visual preset (kicad-cli sch export broken)
    kicad-cli sch export pdf returns exit 3 on this project's .kicad_sch,
    the same way sch export svg did. The format is not the issue —
    something in the schematic file itself is rejected by kicad-cli's
    loader. Until that is diagnosed, KiBot's first-error-stops-everything
    behaviour means the schematic output blocks every render that comes
    after it.
    Visual preset now contains only the three render_3d PNG outputs
    (top, bottom, angled) which do not depend on the schematic. The full
    preset (kibot-full.yaml) keeps schematic outputs because Stage 2-5
    runs are blocking and we want those failures to surface.
2026-05-02 Switch every workflow from KiCad 8 to KiCad 9
    Root cause for every previous CI failure: the project's .kicad_pcb /
    .kicad_sch were saved with KiCad 9 (file format 20241229+), but every
    workflow was using the KiCad 8 toolchain. KiCad 9 files are not
    backwards-compatible — KiCad 8 reports them as 'corrupted' and refuses
    to load. That is why every kicad-cli export returned 3 with no
    diagnostic and every KiBot output returned EXTERNAL_FAIL (17).
    Changes:
    - feature-push.yml uses INTI-CMNB/KiBot@v2_dk9 (was v2_dk8)
    - pr-to-dev/qa/main + release.yml all use the kicad_auto:ki9
    container (was kicad8_auto_full:latest)
    - Restore pdf_schematic in the visual preset — it failed under
    KiCad 8 beca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
2026-05-04 Stage 1 — run ERC/DRC informationally, never block
    Feature pushes were skipping ERC/DRC entirely. Engineers only saw
    issues at PR time, which is too late. Now Stage 1:
    - Runs kicad-cli ERC and DRC, with '|| true' so neither failure mode
    ever exits non-zero. The reports land in output/reports/ and are
    part of the visual-preview artifact.
    - Counts violations into step outputs and renders a job-summary table
    on the run page (visible without downloading the artifact).
    - Generates the same error-report.html as the gated stages so the
    engineer can open one self-contained file with full violation detail.
    - Still produces the schematic PDF, 3D PNG renders, and iBOM via the
    KiBot 'visual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
2026-05-04 Stage 1 — guarantee green run on every feature push
    Pushes to feature branches are never blocked by GitHub itself; CI runs
    after the push lands. But the run can still show red if any step
    exits non-zero, which is misleading for an informational stage.
    - Add continue-on-error: true to every step that could conceivably
    fail (count, error report, job summary, upload).
    - Add a final 'Always succeed' step that explicitly exits 0.
    - ERC/DRC and KiBot steps already had failure tolerance via || true
    and continue-on-error.
    Net effect: feature pushes always show green. Real gating only happens
    at PR-to-dev (Stage 2).
2026-05-04 Replace README with Swasthik_KiBot_Project layout
    - Adopt centered logo/board-name/badges header
    - Add 3D top/bottom angled render images under design/pcb/outputs/Images/
    - Update CI badge to point to Swasthik-FA/Kicad_Template feature-push workflow
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2026-05-04 fix(kibot): use proper isometric rotation steps for 3D angled renders
    KiBot's render_3d rotate_x/y/z and zoom are integer step counts, not
    degrees. Previous values (30/0/20) over-rotated past a usable angle.
    Adopt the reference Fastbit project's tuned values:
    ROTATE_X: 2, ROTATE_Y: -1, ROTATE_Z: ±1, ZOOM: -1
    Z is negated for the bottom view to mirror the top isometric.
    [kibot_main.yaml]
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2026-05-04 Label README PCB renders as Front and Back
    Render the two views as a centered table with fixed 380 px columns so
    the board appears at the same scale on both sides, captioned Front and
    Back underneath.
2026-05-04 Use repo logo and name in README header
    - Replace placeholder Logos/dummy_logo.svg with docs/Kicad_Template.png
    - Set H1 title to the repo name (Kicad_Template)
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2026-05-04 Restructure README hero: angled board render above title
    - Drop the broken Images/dummy_image.png placeholder
    - Move the angled-top render in as a wide hero image directly under the
    logo
    - Keep the board name (H1) and CI badge underneath the hero so the page
    reads logo → board → name → badge → front/back renders
2026-05-04 Revert "Restructure README hero: angled board render above title"
    This reverts commit 92e8fcdeb5639ffdf813906a8bd273e11ba8f2d1.
2026-05-04 Restore README ordering: header → renders → specs → tree
    Move logo, title, and CI badge back to the top, add the missing
    horizontal rule between the front/back render table and the
    Specifications section, and drop the trailing stray rule.
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2026-05-04 Save navigate_results HTML output to top-level HTML/ folder
    Drop the design/pcb/outputs/HTML/ destination; copy KiBot's HTML output
    directly into the repo's top-level HTML/ folder alongside
    error-report.html, so all generated webpages live in one place.
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2026-05-04 Consolidate all generated outputs under HTML/
    Mirror the full KiBot output tree (navigate site + 3d/ + reports/ +
    schematic/ + ibom/) under a single HTML/ folder so the
    navigate_results page's ../3d, ../reports relative links resolve.
    - Drop sibling Images/ and Report/ folders; their content is now at
    HTML/3d/ and HTML/reports/
    - Remove --skip-pre erc,drc so KiBot's preflights produce the
    reports/erc-erc.{html,rpt,json} and drc-drc.* files the navigate
    page links to
    - Workflow wipes HTML/ (preserving .gitkeep) and copies output/ into
    HTML/ on every run
    - README image paths updated to HTML/3d/
2026-05-04 Run KiBot full group on feature push so all nav links resolve
    The navigate_results webpage links to ../assembly/, ../gerbers/,
    ../bom/, ../drill/, ../schematic/, ../ibom/, ../3d/, and ../reports/.
    The visual group only produced four of those, leaving the rest as 404s
    when browsing HTML/HTML/index.html.
    Switching to the full group produces every artifact the navigate site
    references. Feature push is still continue-on-error end-to-end and
    never blocks the build, so the slightly slower run is fine for a
    preview stage.
2026-05-04 Make ERC/DRC navigate links resolve
    Two fixes so the navigate webpage's report buttons open something:
    1. kicad-cli rejected '-f json'. KiCad 9 expects '--format json', so
    the erc.json / drc.json files were never created.
    2. The navigate_results page links to erc-erc.{html,rpt,json} and
    drc-drc.{html,rpt,json}, but KiBot's preflights don't reliably
    produce those filenames in this image. Alias the kicad-cli outputs
    (.rpt, .json) and the styled error-report.html into the
    navigate-expected names before mirroring output/ into HTML/.
2026-05-04 Force navigate report links to download .rpt/.json/...
    - Make alias step explicit and overwrite-safe; log before/after
    contents of output/reports/ so failures are diagnosable
    - After mirroring output/ into HTML/, post-process every navigate_*.html
    page: replace onclick='location.href=URL' with a JS snippet that
    builds a temporary <a download> and clicks it, so clicking links to
    .rpt/.json/.csv/.step/.gbr/.drl/.gbrjob/Gerber files triggers a
    proper file download instead of an inline browser render.
    - HTML reports (erc-erc.html / drc-drc.html) keep the original
    onclick navigation so they open as webpages.
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2026-05-04 Generate separate ERC-only and DRC-only report pages
    Replace the previous behavior of copying the combined error-report.html
    to both erc-erc.html and drc-drc.html. Now invoke generate_error_report.py
    twice: once with just --erc-json/--erc-rpt (yielding an ERC-only page)
    and once with just --drc-json/--drc-rpt (DRC-only). The navigate links
    ERC HTML → ERC-only content; DRC HTML → DRC-only content.
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2026-05-04 ci: run ERC/DRC via KiBot preflight so rule_severities is honored
    - Replace kicad-cli sch erc / kicad-cli pcb drc with a single KiBot --only-pre
    invocation in all four workflows (feature-push, pr-to-dev, pr-to-qa, pr-to-main)
    - kicad-cli ignores .kicad_pro rule_severities overrides, so checks promoted to
    "error" in the project (e.g. hole_clearance) were emitted as warnings and
    silently passed the merge gates on dev/qa/main
    - Update all downstream paths: erc.json -> erc-erc.json, drc.json -> drc-drc.json
    (KiBot's preflight writes those names per kibot_pre_*_report.yaml templates)
    - feature-push: drop the cp loop that was overwriting KiBot's good drc-drc.json
    with kicad-cli's incompl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
2026-05-04 ci: replace --only-pre with KiBot group runs so preflight artifacts are written
    The previous commit used `kibot --only-pre` to run ERC/DRC preflights, but
    in the kicad_auto:ki9 image that flag did not produce the .json/.rpt files
    on disk, so generate_error_report.py ran with empty inputs and the HTML
    reports rendered with neither DRC nor ERC content.
    - feature-push: drop the standalone preflight step; let the existing `full`
    group run preflights as part of its normal flow (no --skip-pre). Move the
    count + generate-report steps to run after the KiBot full group.
    - pr-to-dev/qa/main: replace the preflight step with `kibot ... visual`,
    which always runs preflights and writes erc-erc/drc-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
2026-05-04 Revert "ci: render interactive 3D PCB model in navigate_3d page"
    This reverts commit 6bd4b405a4367433604713a94b7fdbea887c9e68.
2026-05-04 Reapply "ci: render interactive 3D PCB model in navigate_3d page"
    This reverts commit 0bec0eba8568635a9f3271498ae7f535671d5130.
2026-05-04 ci: deploy HTML/ to GitHub Pages so the 3D viewer works on any device
    The <model-viewer> web component only works when the page is served
    over HTTP(S); opening the navigate_3d.html file directly from disk
    fails because Chrome/Edge block ES module loading over file://.
    Deploying HTML/ as a GitHub Pages site gives a stable HTTPS URL that
    works on phones, tablets, and other machines without any local server.
    One-time manual step required:
    Settings -> Pages -> Build and deployment -> Source: "GitHub Actions"
    After that, every push to main or dev that touches HTML/ deploys the
    site automatically. The deployment URL is shown in the job summary
    and on Settings -> Pages.
2026-05-04 Revert "ci: deploy HTML/ to GitHub Pages so the 3D viewer works on any device"
    This reverts commit dcf49e9be20f29b8e1465ee6b28698c7a7bfe19a.
2026-05-04 Revert "Reapply "ci: render interactive 3D PCB model in navigate_3d page""
    This reverts commit e4988cc8c9be68d3f9d7bb4257b36f15a58a1627.
2026-05-04 web: glassmorphism + minimal + dashboard styling
    Combined design pass on the navigate-page theme:
    Glassmorphism
    - Translucent surfaces with backdrop-blur on top bar, sidebar, cards,
    search, and markdown blocks
    - Subtle inner-edge highlight on cards via ::before gloss
    - Mesh-gradient background (three soft radial blobs, fixed attachment)
    - Larger blur radius (22px) and softer borders (rgba 7-12% white)
    Minimal
    - Generous whitespace (heading margins, card padding, line-height 1.6)
    - Restrained monochrome accent (single indigo per section)
    - Lighter borders, cleaner typography hierarchy
    - Removed scrollbar track decoration
    Dashboard
    - Per-category accent colour driven by output-virtual-box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
2026-05-04 web: add vivid colour to the navigate-page theme
    The previous monochrome restraint felt flat. Pump the colour back in
    without breaking the glass+minimal+dashboard structure:
    - Mesh-gradient background: 5 vivid radial blobs (indigo, sky, pink,
    purple, teal) instead of 3 soft ones, ~2x opacity
    - Section heading text now uses a 3-stop gradient fill (accent ->
    accent-strong -> text), tighter tracking, larger weight
    - Heading stripe gets a stronger glow + linear gradient fill
    - Cards have a faint diagonal accent-tinted gradient by default (8%)
    so each category's tile reads as that colour even at rest
    - Card hover: animated conic-gradient ring (rotates over 6s) + accent
    drop shadow, inste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
2026-05-04 ci: re-add interactive 3D PCB model in navigate_3d page
    Bring back the viewer (last reverted in 0bec0eb / adc2c1e):
    - `kicad-cli pcb export glb` produces output/3d/<project>.glb with
    substituted 3D models, copper tracks, and zones.
    - The publish step injects a <model-viewer> panel at the top of
    navigate_3d.html plus a script tag in <head> loading the
    model-viewer web component from jsDelivr.
    - Viewer styling matches the dashboard theme (dark gradient bg, 16px
    radius). Orbit + zoom + pinch controls are enabled.
    Note: <model-viewer> requires HTTP(S). file:// blocks ES module
    loading. View via a local server (`python -m http.server` from HTML/)
    or enable GitHub Pages on the repo. The p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
2026-05-04 Revert "ci: re-add interactive 3D PCB model in navigate_3d page"
    This reverts commit d6388b36cd79d19988f11a1392e99245ff7678d2.
2026-05-04 ci: 3D viewer in navigate_3d page + step file as download button
    Re-add the in-browser 3D viewer:
    - New step exports output/3d/<project>.glb via kicad-cli pcb export glb
    with substituted models, tracks, and zones
    - Publish step injects a <model-viewer> at the top of navigate_3d.html
    (640px, dark gradient background, orbit/zoom/pinch enabled)
    - Poster fallback now explains that file:// will not work and gives
    the exact python -m http.server command and URL to use
    Replace the auto-generated step tile with a clean "Download STEP"
    button:
    - Custom SVG download icon
    - download attribute on the anchor so the browser always saves
    instead of opening
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2026-05-04 ci: drop landing-page viewer embed; rename "3d" tile to "3D Viewer"
    The landing page (navigate.html) doesn't need the heavy 12 MB GLB
    inline — the existing category tile already routes to navigate_3d.html
    which has the working viewer (live on GitHub Pages). Removing the
    landing-page injection keeps the entry point fast.
    Renamed the landing-page "3d" tile label to "3D Viewer" in the publish
    step so the entry point is clearly labelled.
2026-05-05 ci: 3D Viewer = clean button to dedicated Pages page
    Architecture:
    - New dedicated full-screen viewer at HTML/3d-viewer.html (rendered
    in CI from config/web/3d-viewer.html template; placeholders for
    title and GLB URL filled at publish time). Lives at the Pages root,
    so the URL is https://<owner>.github.io/<repo>/3d-viewer.html.
    - The navigate_3d page no longer embeds <model-viewer> inline. Instead
    it gets a clean "3D Viewer" section with a centered call-to-action
    button: cube icon, "Open Interactive 3D Viewer" title, hint about
    the new tab, "Launch viewer ↗" pill. Hover lifts the card and
    glows in indigo. Button URL is the absolute Pages URL (computed
    from GITHUB_REPOSITORY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
2026-05-05 Revert "ci: 3D Viewer = clean button to dedicated Pages page"
    This reverts commit a5aa84cb6b6a893b1bd78b05967c7a02e677ded0.
2026-05-05 ci: navigate_3d page now shows ONLY the 3D viewer
    Strip the auto-generated PNG render tiles (top / bottom / angled-top /
    angled-bottom) and the STEP file tile from navigate_3d.html so the
    page contains nothing but the live <model-viewer>. Clicking the
    landing page's "3D Viewer" tile now lands on a clean viewer-only
    page — no other content.
    The PNG / STEP files still ship under HTML/3d/ (other sections of the
    site or direct URLs can still reach them); only their tiles are
    removed from the navigate_3d main content. The sidebar still lists
    them but the in-page anchors are no-ops on this page.
    The previous "Download STEP" button replacement is gone (that section
    is now stripped entirely).
2026-05-05 Reapply "ci: 3D Viewer = clean button to dedicated Pages page"
    This reverts commit b7d26fde7c5bcd0e3794b82bf7828d5af9c79b1c.
2026-05-05 ci: 3d-viewer page = model-viewer only, no chrome
    Strip the title bar, "Back" button, help hint (drag/scroll/right-drag),
    and their CSS from config/web/3d-viewer.html. The dedicated 3D viewer
    page now contains only the full-screen <model-viewer>, with the
    loading spinner and error message kept (they're feedback for the
    viewer state itself, not extra content).
    Result: clicking "Open Interactive 3D Viewer" lands on a clean
    viewer-only page — just the rotating PCB on the gradient background.
2026-05-05 ci: 3d-viewer page = "Interactive 3D Model" heading + viewer only
    Match the screenshot reference: a small "Interactive 3D Model" label
    in the top-left (with the accent bar + gradient text style that
    matches the navigate page's section headings) and the full-screen
    <model-viewer> below it. No glassmorphic title block, no Back button,
    no help hint, no project-name subtitle — minimal chrome.
    Loader spinner and error fallback are kept (state feedback, not
    content).
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2026-05-05 ci: retarget pipeline to main + add Pages auto-deploy
    After collapsing dev/qa/feature branches into main, the build
    pipeline (feature-push.yml) was inert — it only triggered on
    feature/** branches that no longer exist. And the Pages site was
    stale because no deploy workflow lived on main, so HTML/3d-viewer.html
    (merged in PR #9) never reached Pages -> the "Open Interactive 3D
    Viewer" button hit a 404.
    Two changes:
    - feature-push.yml: trigger changed from feature/** to main.
    Path filter excludes HTML/** to avoid re-triggering on its own
    auto-commit (which already uses [skip ci]). New trigger:
    hardware/**, config/**, scripts/**, the workflow itself.
    - pages.yml: deploy HTML/ to Pages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
2026-05-05 hardware: prune auxiliary libraries and refresh PCB
    Delete vendor footprint/symbol bundles that were lying around
    hardware/ as reference imports — none of them are used by
    Nano-Board-rev-2.kicad_pcb directly:
    - 1x2_Hea/, FPC/, MPU-6050/, SAMTEC-SMH_1x2/,
    USB/, USB MICRO/, USB MICRO 4 NANO/, XKB_microSD.pretty/,
    fp/, stlink-v3mods_cad/
    - LDO/ sub-project (separate board, doesn't belong here)
    - one-off helpers: how-to-import.htm at various paths,
    fabrication-toolkit-options.json, nano (2).csv,
    Backup.gitignore.txt
    - cached pre-built 3D models under hardware/3d/ (KiCad regenerates
    them on demand)
    The PCB itself is updated.
    [47346-0001.step, LDO.kicad_pcb, LDO.kicad_sch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]
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2026-05-06 Revert "ci: refresh 3D PCB renders and README repo name [skip ci]"
    This reverts commit ecf5e19ccf0893330188d003fb74a35d4af01231.
    [Nano-Board-rev-2-B_Cu.gbl, Nano-Board-rev-2-B_Mask.gbs, Nano-Board-rev-2-B_Paste.gbp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]
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2026-05-06 Revert "ci: generate schematic-only landing page when no PCB present"
    This reverts commit f4c3465dee78687d1be3e436cbf72888eb6706d5.
2026-05-06 Revert "ci: support schematic-only projects in feature-push workflow"
    This reverts commit 5d7648416adfecb41536fd25376838f4c48a6221.
    [kibot_main.yaml]
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2026-05-06 ci: swap navigate card for 3D viewer in dynamic landing PCB section
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2026-05-06 ci: skip PCB outputs when only schematic is present
    [kibot_main.yaml]
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2026-05-06 Revert "viewer: default GLB export to board-only for JLCPCB-style view"
    This reverts commit 7259c3de3b4e0a8fdd9b2004c6316c6565cf3508.
2026-05-06 Revert "viewer: switch to JLCPCB-style light background and lighting"
    This reverts commit f152636c7ee8b7318d32c5af8309c5440309829b.
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2026-05-07 feat: add Three.js PCB 3D viewer with auto-deploy via GitHub Pages
    - Add config/web/3d-viewer.html: custom Three.js viewer with OrbitControls,
    GLTFLoader+Meshopt, RoomEnvironment, ACES tonemapping, three-light rig,
    soft shadows; top/bottom/reset/background buttons, loading spinner with
    progress, file:// error fallback, mobile-responsive UI
    - Add scripts/convert_to_glb.py: kicad-cli pcb export glb wrapper
    - feature-push.yml: convert PCB to GLB, compress with gltf-transform
    (Meshopt + webp), render viewer template, link from landing page
    - Restore PCB layout
    [Nano-Board-rev-2.kicad_pcb]
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
